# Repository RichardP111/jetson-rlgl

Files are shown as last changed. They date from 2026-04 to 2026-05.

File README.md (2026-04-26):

<div align="center">

# Jetson RLGL

### A real-time, AI *Red Light, Green Light* Game

A self-officiating *Squid Game*-style game built on the NVIDIA Jetson Orin Nano. The system tracks every player simultaneously with YOLOv8-pose accelerated through TensorRT, detects motion during the red phase to the pixel, identifies eliminated players by shirt colour, and projects the entire game — animated overlays, dramatic eliminations, winner sequences — in real time at 60 FPS.

<br />







<br />

**~30 ms inference · 60 FPS display · multi-player tracking · zero human referee required**

</div>

---

## Table of Contents

- [Performance at a glance](#performance-at-a-glance)
- [How it plays](#how-it-plays)
- [Architecture](#architecture)
- [Hardware](#hardware)
- [Installation](#installation)
- [Running the game](#running-the-game)
- [Calibration tools](#calibration-tools)
- [Configuration](#configuration)
- [Optimisation notes](#optimisation-notes)
- [Troubleshooting](#troubleshooting)
- [Project structure](#project-structure)
- [Credits](#credits)

---

## Performance at a glance

| Metric | Value | How |
|---|---|---|
| Pose inference | **~15–30 ms** | YOLOv8n-pose exported to TensorRT FP16, pre-resized to 640×384 |
| Display loop | **60 FPS** | Decoupled from inference via dedicated `PoseWorker` thread |
| Camera capture | **60 FPS** | CSI IMX219 → NVMM zero-copy → hardware scaler |
| Colour analysis | **~0 ms typical** | Lazy: only runs at catch / win events, not every frame |
| End-to-end latency | **~50 ms** | From a player moving to elimination on screen |

Tested on Jetson Orin Nano (8 GB) with `MAXN` power mode, `jetson_clocks` locked, JetPack 6.0.

---

## How it plays

```
┌────────────────────────────────────────────────────────────┐
│                    START SCREEN                             │
│            Raise a palm for 2 seconds to begin              │
└──────────────────────────────┬─────────────────────────────┘
                               │
                       3 … 2 … 1 …
                               │
┌──────────────────────────────▼─────────────────────────────┐
│                  🟢  GREEN LIGHT                            │
│        Head faces away · Players advance toward finish      │
└──────────────────────────────┬─────────────────────────────┘
                               │  random 3–6 s
┌──────────────────────────────▼─────────────────────────────┐
│                       TURNING                               │
│             Servo rotates · 0.5 s grace window              │
└──────────────────────────────┬─────────────────────────────┘
                               │
┌──────────────────────────────▼─────────────────────────────┐
│                  🔴  RED LIGHT                              │
│      Head faces players · Per-player motion check active    │
│                                                             │
│   Movement detected ──► CAUGHT — return to start            │
│   Timer expires     ──► Back to GREEN                       │
│   Beam crossed      ──► WINNER sequence                     │
└─────────────────────────────────────────────────────────────┘
```

Every player has an independent baseline position the moment red starts. They're checked individually each frame — motion in one person doesn't affect the others. Caught players are identified by shirt colour and announced over a PA speaker by `espeak` TTS: *"Player in the blue shirt — return to the start!"*

---

## Architecture

The system is built around a strict producer-consumer split. Inference runs on its own thread, the camera runs on its own thread, and the main game loop never blocks on either.

```
┌─────────────────────────┐    ┌─────────────────────────┐
│      Camera (thread)    │    │   PoseWorker (thread)   │
│                         │    │                         │
│   nvarguscamerasrc      │───▶│   YOLOv8-pose (TRT FP16)│
│   1280×720 @ 60 FPS     │    │   ~15–30 ms / frame     │
│   ISP-tuned colour      │    │   ByteTrack persistent  │
└──────────┬──────────────┘    └────────────┬────────────┘
           │                                │
           │  latest frame                  │  latest pose
           │  (lock-protected)              │  (lock-protected)
           ▼                                ▼
┌─────────────────────────────────────────────────────────┐
│                    GameEngine (main thread)              │
│                                                          │
│   ┌────────────┐  ┌───────────┐  ┌────────────────────┐ │
│   │ State FSM  │  │   Audio   │  │  ServoController   │ │
│   │ GREEN/RED  │  │  Manager  │  │  (PCA9685, thread) │ │
│   └────────────┘  └───────────┘  └────────────────────┘ │
│                                                          │
│   ┌──────────────────────────────────────────────────┐  │
│   │  UIRenderer — Pygame, 60 FPS Material 3 UI       │  │
│   └──────────────────────────────────────────────────┘  │
└─────────────────────────────────────────────────────────┘
```

Critically, the main loop reads the *most recent* camera frame and the *most recent* pose result — never waits for either. If inference takes 30 ms and the display does 16 ms frames, the game stays at 60 FPS and simply re-uses the most recent pose data for ~2 frames at a time. The eye doesn't notice; the inference budget no longer caps the display.

---

## Hardware

### Bill of materials

| Component | Model | Interface | Notes |
|---|---|---|---|
| Compute | NVIDIA Jetson Orin Nano (8 GB) | — | JetPack 6.0+ |
| Camera | Waveshare IMX219-120 (CSI) | CSI / nvarguscamerasrc | 60 FPS, 120° FOV |
| Servo driver | PCA9685 16-channel PWM | I²C bus 7 @ 0x40 | External 5–6 V supply |
| Servo | Standard 180° hobby servo | PCA9685 ch. 0 | DS3218 or similar |
| Finish line | Laser break-beam module | GPIO physical pin 7 | Active LOW, PUD_UP |
| Audio | PA speaker | 3.5 mm or USB DAC | `espeak` TTS supported |
| Display | Monitor / projector | DP | Native 1920×1080 |

### Wiring

**PCA9685 → Jetson 40-pin header**

| PCA9685 | Jetson | Function |
|:---:|:---:|:---|
| VCC | Pin 1 (3.3 V) | Logic |
| GND | Pin 6 | Ground |
| SDA | Pin 3 | I²C-7 SDA |
| SCL | Pin 5 | I²C-7 SCL |
| **V+** | **External 5–6 V** | **Servo power — DO NOT use Jetson 5V** |

> ⚠️ **Power servos from a separate 5–6 V supply.** Servos can briefly draw >1 A under load; the Jetson rail will sag and reset the board.

**Laser break-beam → Jetson**

| Sensor | Jetson | Note |
|:---:|:---:|:---|
| Signal | Pin 7 (BOARD) | Active LOW, internal pull-up |
| VCC | Pin 1 / 17 (3.3 V) | Most modules also accept 5 V |
| GND | Any GND | Common ground with Jetson |

**Pre-flight verification**

```bash
v4l2-ctl --list-devices         # Camera should appear at /dev/video0
sudo i2cdetect -y 7             # PCA9685 should appear as 40 in the grid
gpio readall                    # Optional — sanity-check pin states
```

---

## Installation

### Prerequisites

- Jetson Orin Nano with JetPack 6.0 or later
- CUDA, cuDNN, TensorRT (all bundled with JetPack)
- A working DISPLAY — local HDMI, or NoMachine for headless
- ~3 GB free disk space

### Setup

```bash
git clone https://github.com/RichardP111/jetson-rlgl.git
cd jetson-rlgl
bash setup.sh
```

`setup.sh` installs `ultralytics`, `pygame`, `adafruit-circuitpython-pca9685`, `Jetson.GPIO`, `espeak`, `v4l-utils`, and `i2c-tools`. It also verifies the camera node and I²C bus.

### One-time TensorRT export

The repo ships with `yolov8n-pose.pt`. On first run the engine is auto-built — but you can trigger it manually for predictable startup time:

```bash
yolo export model=yolov8n-pose.pt format=engine half=True imgsz=480 device=0
```

This takes **~5 minutes** the first time. The resulting `yolov8n-pose.engine` is what `vision.py` actually loads.

### Lock the Jetson at full clocks (recommended)

```bash
sudo nvpmodel -m 0          # MAXN power mode
sudo jetson_clocks          # Pin clocks to maximum
```

Without this, dynamic frequency scaling causes inference times to fluctuate by ~30%.

### Assets

Drop your media into the assets folders:

**`assets/sounds/`** — all optional; `espeak` TTS is the fallback.

| File | Used for |
|---|---|
| `bgm.mp3` | Background music loop |
| `green_light.wav` | Green-light cue |
| `red_light.wav` | Red-light cue |
| `mugunghwa.wav` | Korean "freeze" phrase |
| `eliminated.wav` | Caught sting |
| `winner.wav` | Victory fanfare |
| `tick.wav` / `chime.wav` | Countdown / generic |

**`assets/fonts/`** — `GoogleSans-Bold.ttf` recommended (Material 3 default).

---

## Running the game

```bash
bash launcher.sh
```

`launcher.sh` is a menu-driven controller that handles the hairy stuff: display permissions, `nvargus-daemon` restart, audio device routing, and Docker container coordination. Pick option **3** to start the game.

To bypass the launcher (developer mode):

```bash
export DISPLAY=:0
python3 main.py
```

### Debug hotkeys

These are live during gameplay and useful for testing without playing through the full FSM.

| Key | Action |
|:---:|---|
| `H` | Toggle on-screen debug panel (FPS, inference ms, player count) |
| `G` | Force GREEN LIGHT |
| `R` | Force RED LIGHT |
| `W` | Force WINNER screen |
| `E` | Simulate elimination |
| `SPACE` | Skip palm-raise gesture |
| `ESC` | Graceful shutdown |

---

## Calibration tools

Three standalone GUIs are bundled to handle hardware bring-up, tuning, and debugging without modifying the game code. Each writes a snippet you paste back into `config.py` (or `hardware.py` for the camera).

### `test_camera.py` — ISP & colour

```bash
python3 test_camera.py
```

Live preview with sliders for every `nvarguscamerasrc` knob — white balance, saturation, exposure, gain caps, ISP digital gain, temporal noise reduction, edge enhancement. Tabbed by category. Shows the GStreamer pipeline string updating in real time, and emits a drop-in `_gstreamer_pipeline()` snippet for `hardware.py`. Includes presets for fluorescent gym lighting, daylight, and warm tungsten.

**Most useful for:** colours looking dull or grey, sensor noise in low light, AE/AWB hunting causing blur cycles.

### `test_servo.py` — PCA9685

```bash
python3 test_servo.py
```

Animated semicircular gauge, manual angle and pulse-width sliders, four automated tests (sweep / step response / hold / random walk), I²C bus scanner, PCA9685 ping, and a guided MIN/MAX calibration wizard. Hard-stop protection — won't drive past mechanical limits once calibrated. Generates the full servo block for `config.py`.

**Most useful for:** first-time install, finding your specific servo's real `MIN_US`/`MAX_US`, debugging jitter or buzzing.

### `tets_lazer.py` — Break-beam

```bash
python3 tets_lazer.py
```

Live beam-state visualisation, scrolling 10-second history strip (great for spotting flaky sensors), debounce calibration with samples × window, and three automated tests:

- **Alignment helper** — confirms a stable beam for 10 seconds straight
- **Drift watch** — 60-second false-positive logger
- **Latency probe** — measures debounce delay across 10 real crossings

GPIO diagnostics tab runs all the standard checks (gpio group membership, gpiochip device list, current pin state).

**Most useful for:** the day-of-event debugging when a previously-working sensor has decided to act up, alignment after physical setup, dialing in debounce so a single crossing isn't counted as five wins.

All three tools fall back to **simulation mode** when hardware isn't available, so they're useful for UI testing on a laptop too.

---

## Configuration

Everything tunable lives in `config.py`. The values most worth knowing:

### Gameplay timing

```python
GREEN_LIGHT_MIN  = 3.0   # shortest green-light phase
GREEN_LIGHT_MAX  = 6.0   # longest green-light phase
RED_LIGHT_MIN    = 2.0   # shortest red-light phase
RED_LIGHT_MAX    = 5.0   # longest red-light phase
GRACE_PERIOD     = 0.5   # delay after RED before motion can catch
MOTION_THRESHOLD = 15.0  # pixels of movement to trigger elimination
CAUGHT_HOLD      = 3.5   # screen pause after a catch
```

`MOTION_THRESHOLD` is in pixel space at 1280×720 capture resolution. If you change camera resolution, scale this proportionally — at 960×540 you'd want `~11`.

### Difficulty presets

For age-appropriate scaling, three pre-tuned profiles ship in `config.py`:

| Preset | Green min/max | Red min/max | Motion px |
|---|:---:|:---:|:---:|
| Easy | 5.0 – 9.0 s | 4.0 – 7.0 s | 20 |
| **Normal** | 3.5 – 7.0 s | 3.0 – 5.5 s | 15 |
| Hard | 2.5 – 5.0 s | 2.0 – 4.0 s | 10 |

### Hardware pinout

```python
I2C_BUS         = 7        # Bus 7 on Orin Nano 40-pin header
PCA9685_ADDRESS = 0x40
SERVO_CHANNEL   = 0
SERVO_FREQ      = 50       # Hz; some cheap servos prefer 60
SERVO_MIN_PULSE = 500      # µs — calibrate per-servo with servo_tuner.py
SERVO_MAX_PULSE = 2500     # µs
LASER_PIN       = 7        # BOARD numbering
```

---

## Optimisation notes

The system has been optimised hard. The key wins, in order of impact:

1. **TensorRT FP16 export.** ~100 ms PyTorch inference → ~15–30 ms TRT inference. Single biggest win.
2. **Pre-resize the YOLO input.** Feeding 1920×1080 frames into a 480-input model wastes ~5 ms per frame on a CPU-side letterbox. Pre-sizing to 640×384 in OpenCV cuts that to ~1 ms.
3. **Async `PoseWorker` thread.** Decouples display loop from inference. Display fps is now bounded by `FPS_CAP`, not by YOLO.
4. **Lazy shirt-colour detection.** Eleven `cv2.inRange` operations per detected player, every frame, was costing ~3–6 ms with multiple players. Now runs only at catch / winner events — saves several ms continuously.
5. **ISP-tuned camera pipeline.** Saturation boost, white balance lock, digital gain capped at 1× to kill amplification noise, edge enhancement disabled. Better-looking image *and* faster — no more per-frame CPU colour correction.
6. **Power mode.** `nvpmodel -m 0` + `jetson_clocks` is free 30% perf.

If inference is still slow after all of this, drop to `imgsz=384` in the export command. INT8 export shaves another few milliseconds but requires calibration data and slightly hurts keypoint accuracy on small bodies.

---

## Troubleshooting

| Symptom | First thing to check |
|---|---|
| **Black camera feed** | `v4l2-ctl --list-devices` — if empty, run `sudo /opt/nvidia/jetson-io/jetson-io.py` and enable IMX219 |
| **PCA9685 not detected** | `sudo i2cdetect -y 7` — should show `40`. If not, check SDA/SCL wiring |
| **GPIO permission denied** | `sudo usermod -aG gpio $USER && sudo reboot` |
| **Servo jitters / buzzes** | Power supply too weak. Use a separate 5–6 V supply, ≥1 A. Common ground required. |
| **Beam triggers spuriously** | Run `laser_tuner.py` → Drift Watch test. Increase debounce samples to 5+ |
| **Inference > 50 ms** | Confirm `.engine` is loading, not `.pt`. Check `sudo nvpmodel -q` shows MAXN |
| **Display fps < 60** | Check `FPS_CAP=60` in `config.py`. Confirm `PoseWorker` is publishing pose only, not frames |
| **Colours look grey / dull** | Run `camera_tuner.py` — bump saturation to 1.4, lock AWB after calibration |
| **NoMachine no display** | `export DISPLAY=:1` (NoMachine virtual session, not `:0`) |

For each hardware subsystem, the matching tuner script has a dedicated **Troubleshooting** tab with extended checklists.

---

## Project structure

```
jetson-rlgl/
├── main.py                 Entry point — initialises subsystems, runs engine
├── game.py                 GameEngine — finite-state machine, motion logic
├── vision.py               ProPoseTracker (TRT) + PoseWorker (async thread)
├── ui.py                   UIRenderer — Material 3 Pygame screens
├── audio.py                AudioManager — SFX + music + espeak TTS
├── hardware.py             Camera (CSI), ServoController (PCA9685), LaserBreakBeam
├── config.py               All tunable constants + difficulty presets
│
├── camera_tuner.py         ISP / GStreamer live tuner
├── servo_tuner.py          PCA9685 calibration & test rig
├── laser_tuner.py          GPIO break-beam debugger
│
├── setup.sh                One-shot dependency installer
├── launcher.sh              Menu-driven game launcher
│
├── yolov8n-pose.pt         Source model (4 MB)
├── yolov8n-pose.engine     TensorRT engine, auto-generated on first run (~10 MB)
│
├── assets/
│   ├── fonts/              GoogleSans .ttf files
│   └── sounds/             .wav and .mp3 audio
│
└── hardware_tests/         Standalone subsystem test scripts
```

---

## Built with

[NVIDIA Jetson](https://www.nvidia.com/en-us/autonomous-machines/embedded-systems/) ·
[TensorRT](https://developer.nvidia.com/tensorrt) ·
[YOLOv8 by Ultralytics](https://github.com/ultralytics/ultralytics) ·
[OpenCV](https://opencv.org/) ·
[GStreamer](https://gstreamer.freedesktop.org/) ·
[Pygame](https://www.pygame.org/) ·
[Adafruit CircuitPython](https://github.com/adafruit/Adafruit_CircuitPython_PCA9685) ·
[espeak](http://espeak.sourceforge.net/)

---
## Acknowledgements

### Models
- **YOLOv8-pose** by [Ultralytics](https://github.com/ultralytics/ultralytics)
  — released under [AGPL-3.0](https://github.com/ultralytics/ultralytics/blob/main/LICENSE).
  The bundled `yolov8n-pose.pt` and the derived `yolov8n-pose.engine`
  remain under AGPL. Code in this repository that loads or wraps these
  weights is intended for personal and educational use; commercial
  deployment requires either an Ultralytics enterprise license or
  AGPL-compatible release of all dependent code.

### Fonts
- **Google Sans** by Google — licensed under
  [SIL Open Font License v1.1](assets/fonts/OFL.txt). Redistributed
  unmodified.

### Inspiration
- The *Red Light, Green Light* game itself is a traditional
  playground game in the public domain.
- Aesthetic and dramatic framing inspired by *Squid Game* (Netflix, 2021).
  This project is not affiliated with, endorsed by, or sponsored by
  Netflix or any related entity. All series-specific trademarks,
  character likenesses, and copyrighted material remain the property
  of their respective owners.

### Author
Built by **Richard P** and **Cindy X** for STEM Day 2026.

Released under the [MIT License](LICENSE) — note that this license
applies to the project's original code only. Bundled third-party
assets (fonts, model weights) retain their original licenses.

<br />

<div align="center">

*"red light…   green light…"*

</div>

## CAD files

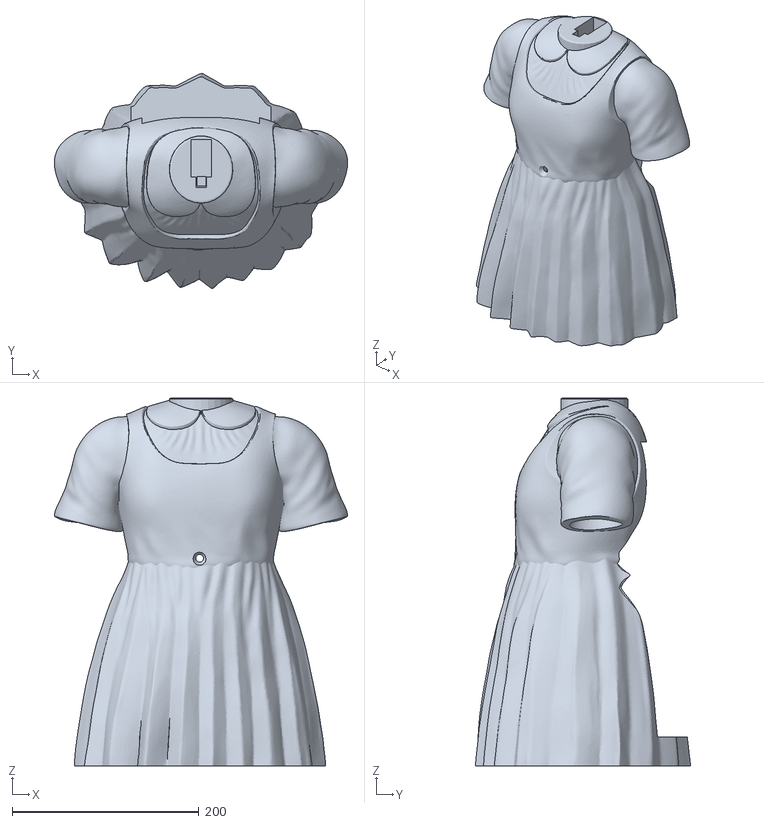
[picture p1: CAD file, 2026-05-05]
3D_files/RLGL BODY.stl
314.2 x 230.4 x 394.2

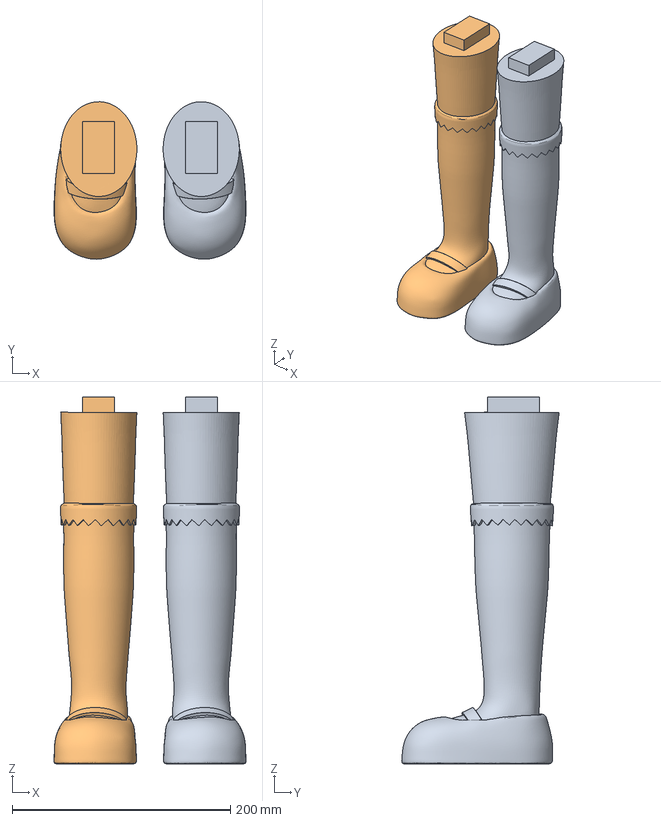
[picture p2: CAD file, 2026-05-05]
3D_files/RLGL LEGS.3mf
175.9 x 144.4 x 336.5 mm
Leg_L.stl
leg_R.stl

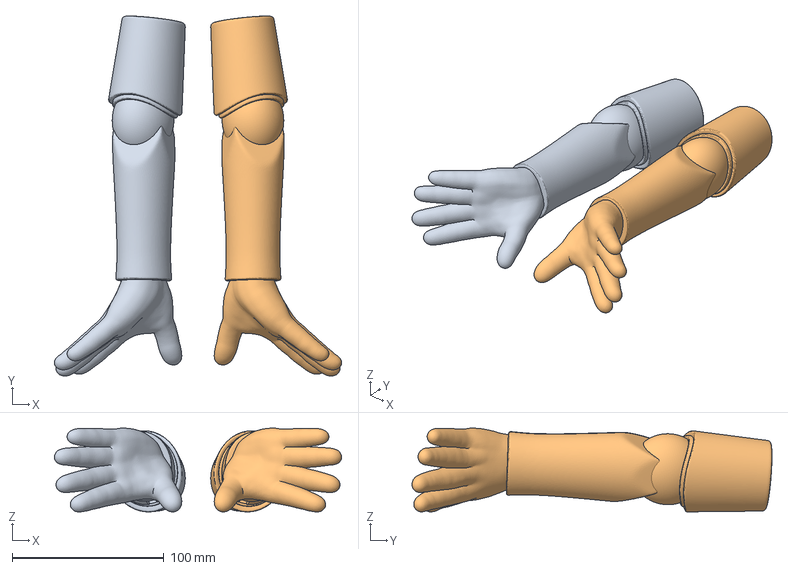
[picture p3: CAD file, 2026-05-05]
3D_files/RLGL ARMS.3mf
189.6 x 237.5 x 55.3 mm
arm_L.stl
arm_R.stl

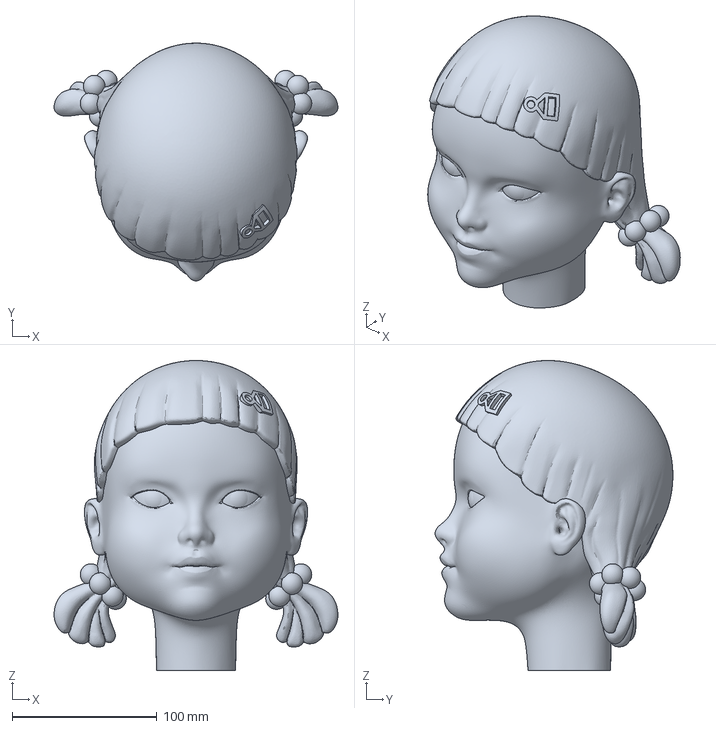
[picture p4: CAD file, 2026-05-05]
3D_files/RLGL HEAD.3mf
196.2 x 164.4 x 214.3 mm

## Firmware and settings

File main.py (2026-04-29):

#!/usr/bin/env python3
# -*- coding: utf-8 -*-

"""
===============================================================================
Project:      Red Light Green Light (Jetson Orin Nano)
File:         main.py
Description:  Entry point — initialises all subsystems and hands off to GameEngine.

Author:       Richard Pu
Last Updated: April 2026

To Run:
Run laucher.sh OR VS CODE: Ctrl+Shift+B
===============================================================================
"""

from __future__ import annotations

import argparse
import os
import sys
import traceback

# Headless support (must be set before pygame imports a display module)
if "--headless" in sys.argv or os.environ.get("RLGL_HEADLESS") == "1":
    os.environ.setdefault("SDL_VIDEODRIVER", "dummy")
    os.environ.setdefault("SDL_AUDIODRIVER", "dummy")
else:
    # Apr 2026 — force GPU compositing on Jetson Orin Nano. Pygame's
    # default SDL2 backend on Linux silently falls back to a software
    # blit pipeline, which pegs a single CPU core and leaves the GPU
    # idle. Telling SDL to use the OpenGL ES 2 renderer offloads the
    # final framebuffer composite to the Jetson's integrated GPU and
    # frees the CPU up for camera + pose work.
    #
    # Setting these as DEFAULTS via setdefault() lets the user override
    # them from the shell if a particular system needs something else
    # (e.g. SDL_RENDER_DRIVER=opengl on a desktop dev box).
    os.environ.setdefault("SDL_RENDER_DRIVER", "opengles2")
    os.environ.setdefault("SDL_RENDER_VSYNC", "1")
    # On Jetson, KMSDRM gives us a clean fullscreen path without going
    # through X11; keep it as a fallback if the user is running headless
    # without a desktop.
    if not os.environ.get("DISPLAY") and not os.environ.get("WAYLAND_DISPLAY"):
        os.environ.setdefault("SDL_VIDEODRIVER", "kmsdrm")

import pygame

# Audio pre_init must happen BEFORE pygame.init() to set the mixer buffer
import audio as audio_mod

audio_mod.pre_init()

from audio import AudioManager
from config import (
    DISPLAY_H,
    DISPLAY_W,
    FPS_CAP,
    IDENTIFICATION_MODE,
    USE_LASER,
    USE_TAPE_FINISH,
    WINDOW_TITLE,
)
from game import GameEngine
from hardware import Camera, LaserBreakBeam, ServoController
from ui import UIRenderer
from vision import PlayerDescriber, PoseWorker, ProPoseTracker


# ---------------------------------------------------------------------------
# Pretty banner
# ---------------------------------------------------------------------------
_BANNER = r"""
╔══════════════════════════════════════════════════════════════════════════╗
║                                                                          ║
║      RED LIGHT, GREEN LIGHT  ·  Jetson Orin Nano  ·  Apr 2026            ║
║                                                                          ║
║      • Camera + (optional) laser break-beam finish detection             ║
║      • YOLOv8-pose tracking, palm-raise to start                         ║
║      • {id_mode_pad}player identification (VLM / CLIP / colour)        ║
║      • Auto-easing difficulty if a round drags on                        ║
║      • Kahoot-style leaderboard with podium photos                       ║
║                                                                          ║
║      HOTKEYS:  H or Ctrl+D  Dev panel                                    ║
║                G              Force GREEN  (begins round if needed)      ║
║                R              Force RED                                  ║
║                W              Debug-finish first remaining player        ║
║                L              Jump to leaderboard                        ║
║                F              Toggle DEBUG_SKIP_FINISH (no finish line)  ║
║                SPACE          Bypass palm gate / Play again              ║
║                ESC            Quit                                       ║
║      DEV-ONLY: 1 servo→face   2 servo→away   3 laser status              ║
║                4 chime         5 TTS test                                ║
║                                                                          ║
╚══════════════════════════════════════════════════════════════════════════╝
"""


def _print_banner() -> None:
    print(_BANNER.format(id_mode_pad=f"{IDENTIFICATION_MODE:>5} "))
    print(f"  USE_LASER       = {USE_LASER}")
    print(f"  USE_TAPE_FINISH = {USE_TAPE_FINISH}")
    print(f"  ID mode         = {IDENTIFICATION_MODE}")
    print()


# ---------------------------------------------------------------------------
# Main
# ---------------------------------------------------------------------------
def main() -> int:
    parser = argparse.ArgumentParser()
    parser.add_argument("--headless", action="store_true", help="Run with dummy SDL drivers (no display, no audio device)")
    parser.add_argument("--fullscreen", action="store_true", default=True, help="Run fullscreen (default)")
    parser.add_argument("--windowed", dest="fullscreen", action="store_false", help="Run in a window (useful for dev)")
    args = parser.parse_args()

    _print_banner()

    pygame.init()
    pygame.display.set_caption(WINDOW_TITLE)
    # Apr 2026 — pygame.SCALED routes the framebuffer through SDL2's
    # GPU-accelerated renderer (matched with SDL_RENDER_DRIVER=opengles2
    # set above) and DOUBLEBUF gives us a proper backbuffer flip rather
    # than a software blit. Together with the SDL hints these flags are
    # what actually gets the Jetson GPU off idle.
    base_flags = pygame.SCALED | pygame.DOUBLEBUF
    if args.fullscreen and not args.headless:
        base_flags |= pygame.FULLSCREEN
    try:
        screen = pygame.display.set_mode((DISPLAY_W, DISPLAY_H), base_flags, vsync=1)
    except Exception as exc:
        # SDL_RENDER_DRIVER=opengles2 + SCALED can fail on systems without
        # a working GLES2 stack; fall back to plain DOUBLEBUF so we at
        # least keep DOUBLEBUF's flip-buffer benefit.
        print(f"[main] GPU display path unavailable ({exc}); falling back to plain DOUBLEBUF")
        fallback_flags = pygame.DOUBLEBUF
        if args.fullscreen and not args.headless:
            fallback_flags |= pygame.FULLSCREEN
        screen = pygame.display.set_mode((DISPLAY_W, DISPLAY_H), fallback_flags)
    pygame.mouse.set_visible(False)
    clock = pygame.time.Clock()

    # ---- Construct subsystems ----------------------------------------
    camera: Camera | None = None
    servo: ServoController | None = None
    laser: LaserBreakBeam | None = None
    tracker: ProPoseTracker | None = None
    pose_worker: PoseWorker | None = None
    audio: AudioManager | None = None
    ui: UIRenderer | None = None
    describer: PlayerDescriber | None = None

    rc = 0
    try:
        camera = Camera()
        servo = ServoController()
        laser = LaserBreakBeam()
        tracker = ProPoseTracker()
        pose_worker = PoseWorker(camera, tracker)
        audio = AudioManager()
        ui = UIRenderer(screen)
        ui.set_audio_hook(audio)  # let the leaderboard fire podium SFX directly
        describer = PlayerDescriber()
        print("[main] Warming up describer...")
        if IDENTIFICATION_MODE == "vlm":
            describer._ensure_vlm()
        elif IDENTIFICATION_MODE == "clip":
            describer._ensure_clip()

        engine = GameEngine(
            camera=camera,
            servo=servo,
            laser=laser,
            tracker=tracker,
            audio=audio,
            ui=ui,
            pose_worker=pose_worker,
            describer=describer,
        )
        engine.run(clock)
    except SystemExit:
        pass
    except KeyboardInterrupt:
        print("\n[main] Interrupted.")
    except Exception as exc:
        print(f"[main] Fatal: {exc}")
        traceback.print_exc()
        rc = 1
    finally:
        # Reverse-order teardown
        try:
            if pose_worker is not None:
                pose_worker.stop()
        except Exception:
            pass
        try:
            if camera is not None:
                camera.release()
        except Exception:
            pass
        try:
            if servo is not None:
                servo.cleanup()
        except Exception:
            pass
        try:
            if laser is not None:
                laser.cleanup()
        except Exception:
            pass
        try:
            if audio is not None:
                audio.cleanup()
        except Exception:
            pass
        try:
            pygame.quit()
        except Exception:
            pass

    return rc


if __name__ == "__main__":
    raise SystemExit(main())

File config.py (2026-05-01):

#!/usr/bin/env python3
# -*- coding: utf-8 -*-

"""
===============================================================================
Project:      Red Light Green Light (Jetson Orin Nano)
File:         config.py
Description:  Global constants, M3 Expressive palette, tunable difficulty,
              animation timings, and hardware pin definitions.

Author:       Richard Pu
Last Updated: April 2026
===============================================================================
"""

import os
import platform

# ---------------------------------------------------------------------------
# Platform detection
# ---------------------------------------------------------------------------
IS_WINDOWS = platform.system() == "Windows"
IS_LINUX = platform.system() == "Linux"

# ---------------------------------------------------------------------------
# Paths
# ---------------------------------------------------------------------------
BASE_DIR = os.path.dirname(os.path.abspath(__file__))
ASSETS_DIR = os.path.join(BASE_DIR, "assets")
FONTS_DIR = os.path.join(ASSETS_DIR, "fonts")
SOUNDS_DIR = os.path.join(ASSETS_DIR, "sounds")
PROFILES_DIR = os.path.join(ASSETS_DIR, "player_profiles")
STATS_FILE = os.path.join(ASSETS_DIR, "session_stats.json")
LEADERBOARD_FILE = os.path.join(ASSETS_DIR, "leaderboard.json")
FONT_PATH = os.path.join(FONTS_DIR, "GoogleSans.ttf")

# ---------------------------------------------------------------------------
# Display
# ---------------------------------------------------------------------------
DISPLAY_W = 1920
DISPLAY_H = 1080
FPS_CAP = 60
FULLSCREEN = True
WINDOW_TITLE = "Red Light, Green Light"

# ---------------------------------------------------------------------------
# Camera
# ------------_--------------------------------------------------------------
CAM_W = 1920
CAM_H = 1080
CAM_FPS = 30
YOLO_SKIP_FRAMES = 2  # How many camera frames between YOLO inferences
HOME_CAM_BOX_FRACTION = 0.6  # Camera occupies 60% of usable width on home screen

# ---------------------------------------------------------------------------
# Material Design 3 "Expressive" palette
# ---------------------------------------------------------------------------

# Surfaces
MD3_BG = (18, 16, 26)
MD3_SURFACE = (28, 26, 38)
MD3_SURFACE_HIGH = (40, 37, 54)
MD3_SURFACE_VAR = (50, 46, 68)
MD3_OUTLINE = (78, 74, 96)

# Primary
MD3_PRIMARY = (188, 162, 255)
MD3_ON_PRIMARY = (28, 0, 90)
MD3_PRIMARY_CONTAINER = (64, 46, 122)
MD3_ON_PRIMARY_CONTAINER = (232, 221, 255)

# Secondary
MD3_SECONDARY = (255, 180, 200)
MD3_ON_SECONDARY = (80, 25, 50)

# Tertiary
MD3_TERTIARY = (120, 220, 232)
MD3_ON_TERTIARY = (0, 55, 62)

# Semantic
MD3_SUCCESS = (168, 232, 178)
MD3_SUCCESS_ON = (0, 74, 24)
MD3_SUCCESS_BG = (36, 70, 44)

MD3_ERROR = (255, 182, 180)
MD3_ERROR_ON = (94, 17, 24)
MD3_ERROR_BG = (92, 36, 40)

MD3_WARNING = (255, 220, 160)
MD3_WARNING_ON = (76, 48, 0)
MD3_WARNING_BG = (96, 64, 16)

MD3_INFO = (180, 210, 255)
MD3_INFO_ON = (8, 36, 92)

# Podium
MD3_GOLD = (255, 215, 96)
MD3_SILVER = (200, 208, 220)
MD3_BRONZE = (217, 150, 100)

# Text
MD3_ON_BG = (235, 228, 245)
MD3_ON_BG_MED = (188, 182, 200)
MD3_ON_BG_DIM = (128, 122, 142)

# Per-state accent (used by the banner)
STATE_COLORS = {
    "START": MD3_PRIMARY,
    "COUNTDOWN": MD3_TERTIARY,
    "GREEN": MD3_SUCCESS,
    "TURNING": MD3_WARNING,
    "RED": MD3_ERROR,
    "CAUGHT": MD3_ERROR,
    "ELIMINATED": MD3_ERROR,  # walk-back banner colour (Apr 2026 rebrand)
    "WINNER": MD3_PRIMARY,
    "START_LINE": MD3_SUCCESS,
    "RETURN": MD3_ERROR,  # legacy alias kept for compatibility
    "LEADERBOARD": MD3_PRIMARY,
}

# ---------------------------------------------------------------------------
# Motion
# ---------------------------------------------------------------------------
MOTION_FAST = 18.0
MOTION_MED = 10.0
MOTION_SLOW = 6.0
BANNER_PULSE_HZ = 1.4

# ---------------------------------------------------------------------------
# Gameplay timing — slower-paced defaults per Apr 2026 design refresh
# ---------------------------------------------------------------------------
DIFFICULTY_PRESETS = {
    "Easy": {
        "green_min": 7.0,
        "green_max": 13.0,
        "red_min": 5.0,
        "red_max": 9.0,
        "motion_px": 28,
    },
    "Normal": {
        "green_min": 1.0,
        "green_max": 2.0,
        "red_min": 4.0,
        "red_max": 7.5,
        "motion_px": 26,
    },
    "Hard": {
        "green_min": 3.5,
        "green_max": 7.0,
        "red_min": 3.0,
        "red_max": 5.5,
        "motion_px": 14,
    },
}
DEFAULT_DIFFICULTY = "Normal"
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

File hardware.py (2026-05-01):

#!/usr/bin/env python3
# -*- coding: utf-8 -*-

"""
===============================================================================
Project:      Red Light Green Light (Jetson Orin Nano)
File:         hardware.py
Description:  Platform-aware hardware abstraction.


Author:       Richard Pu
Last Updated: April 2026
===============================================================================
"""

from __future__ import annotations

import threading
import time
from typing import Any

import cv2  # type: ignore
import numpy as np

from config import (
    CAM_FPS,
    CAM_H,
    CAM_W,
    I2C_BUS,
    IS_LINUX,
    IS_WINDOWS,
    LASER_PIN,
    PCA9685_ADDR,
    SERVO_AWAY_DEG,
    SERVO_CHANNEL,
    SERVO_FACE_DEG,
    SERVO_FREQ,
    SERVO_MAX_US,
    SERVO_MIN_US,
    SERVO_STEP_DEG,
    SERVO_TICK_S,
    USE_LASER,
)

# ---------------------------------------------------------------------------
# Optional Jetson-only imports.
# ---------------------------------------------------------------------------
_ADAFRUIT_OK = False
_GPIO_OK = False

if IS_LINUX:
    try:
        import board  # type: ignore
        import busio  # type: ignore
        from adafruit_pca9685 import PCA9685 as _PCA9685  # type: ignore

        _ADAFRUIT_OK = True
    except (ImportError, AttributeError, NotImplementedError, ValueError):
        _ADAFRUIT_OK = False

    try:
        import Jetson.GPIO as GPIO  # type: ignore

        _GPIO_OK = True
    except (ImportError, AttributeError, RuntimeError):
        _GPIO_OK = False

HARDWARE_AVAILABLE = _ADAFRUIT_OK or _GPIO_OK


# ---------------------------------------------------------------------------
# Camera
# ---------------------------------------------------------------------------
def _gstreamer_pipeline(
    capture_w: int = CAM_W,
    capture_h: int = CAM_H,
    output_w: int = 1920,
    output_h: int = 1080,
    fps: int = CAM_FPS,
) -> str:
    return (
        f"nvarguscamerasrc "
        f"wbmode=2 "
        f"saturation=1.01 "
        f'gainrange="1 8" '
        f'ispdigitalgainrange="1 1" '
        f'exposuretimerange="13000 16000000" '
        f"tnr-mode=2 tnr-strength=0.2 "
        f"exposurecompensation=1.14 "
        f"ee-mode=0 "
        f"aelock=false awblock=false "
        f"! video/x-raw(memory:NVMM), width={capture_w}, height={capture_h}, "
        f"format=NV12, framerate={fps}/1 ! "
        f"nvvidconv flip-method=2 ! "
        f"video/x-raw, width={output_w}, height={output_h}, format=BGRx ! "
        f"videoconvert ! video/x-raw, format=BGR ! "
        f"appsink drop=true max-buffers=1"
    )


class Camera:
    """Threaded camera capture with a single shared frame guarded by a lock.

    Producer: background daemon thread.
    Consumer: main loop calls read() / read_with_id() each frame.
    """

    def __init__(self) -> None:
        self._lock = threading.Lock()
        self._frame: np.ndarray | None = None
        self._running = True
        self._ok = False
        self._backend = "none"
        self._fps_ts = time.time()
        self._fps_count = 0
        self._fps = 0.0
        self._frame_id = 0
        self._cap = self._open()

        self._thread = threading.Thread(target=self._loop, daemon=True, name="cam")
        self._thread.start()
        print(f"[CAM] Backend: {self._backend}  ok={self._ok}")

    def _open(self) -> Any | None:
        video_capture = getattr(cv2, "VideoCapture", None)
        if video_capture is None:
            self._backend = "none"
            self._ok = False
            return None

        if IS_WINDOWS:
            return self._open_default(video_capture)

        cap_gstreamer = int(getattr(cv2, "CAP_GSTREAMER", 0))
        cap = video_capture(_gstreamer_pipeline(), cap_gstreamer)
        if cap.isOpened():
            self._backend = "gstreamer"
            self._ok = True
            return cap

        cap_v4l2 = int(getattr(cv2, "CAP_V4L2", 0))
        cap = video_capture(0, cap_v4l2)
        if cap.isOpened():
            cap.set(int(getattr(cv2, "CAP_PROP_FRAME_WIDTH", 3)), CAM_W)
            cap.set(int(getattr(cv2, "CAP_PROP_FRAME_HEIGHT", 4)), CAM_H)
            cap.set(int(getattr(cv2, "CAP_PROP_FPS", 5)), CAM_FPS)
            cap.set(int(getattr(cv2, "CAP_PROP_BUFFERSIZE", 38)), 1)
            self._backend = "v4l2"
            self._ok = True
            return cap

        return self._open_default(video_capture)

    def _open_default(self, video_capture: Any | None = None) -> Any | None:
        if video_capture is None:
            video_capture = getattr(cv2, "VideoCapture", None)
            if video_capture is None:
                self._backend = "none"
                self._ok = False
                return None

        cap = video_capture(0)
        if cap.isOpened():
            cap.set(int(getattr(cv2, "CAP_PROP_FRAME_WIDTH", 3)), CAM_W)
            cap.set(int(getattr(cv2, "CAP_PROP_FRAME_HEIGHT", 4)), CAM_H)
            self._backend = "default"
            self._ok = True
            return cap
        self._backend = "none"
        self._ok = False
        return None

    def _loop(self) -> None:
        while self._running:
            if self._cap is not None and self._ok:
                ret, frame = self._cap.read()
                if ret and frame is not None:
                    with self._lock:
                        self._frame = frame
                        self._frame_id += 1
                    self._fps_count += 1
                    now = time.time()
                    if now - self._fps_ts >= 1.0:
                        self._fps = self._fps_count / (now - self._fps_ts)
                        self._fps_count = 0
                        self._fps_ts = now
                else:
                    time.sleep(0.01)
            else:
                time.sleep(0.033)
            time.sleep(0.001)

    def read(self) -> np.ndarray | None:
        with self._lock:
            if self._frame is None:
                return None
            return self._frame.copy()

    def read_with_id(self) -> tuple[np.ndarray | None, int]:
        """Return a copy of the latest frame and a monotonic frame id.

        The id is incremented each time the camera thread stores a new frame.
        Callers can use it to skip expensive work when no new frame arrived.
        """
        with self._lock:
            if self._frame is None:
                return None, self._frame_id
            return self._frame.copy(), self._frame_id

    @property
    def ok(self) -> bool:
        return self._ok

    @property
    def backend(self) -> str:
        return self._backend

    @property
    def fps(self) -> float:
        return self._fps

    def release(self) -> None:
        self._running = False
        self._thread.join(timeout=1.5)
        if self._cap is not None:
            try:
                self._cap.release()
            except Exception:
                pass
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

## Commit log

2026-04-19 Refactor AudioManager to use player_label in elimination announcements; update GameEngine to integrate YOLO tracking and color analysis for player identification; replace PoseTracker with ProPoseTrac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
    [audio.py, game.py, test_laser.py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]
2026-04-19 Refactor vision.py: Enhance shirt color detection and implement pose tracking with skeleton overlay
    - Removed the old ColorAnalyzer class and replaced it with a more efficient get_shirt_colour function using HSV color space.
    - Introduced a new PoseTracker class that wraps YOLOv8-pose for persistent tracking and skeleton drawing.
    - Added functionality to process frames, extract keypoints, and draw skeletons on the detected persons.
    - Implemented palm-raise gesture detection and finish-line tape detection based on pose data.
    - Improved code organization and readability by restructuring functions and constants.
    [audio.py, config.py, game.py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]
2026-04-21 Refactor audio and hardware management: Implement Docker compatibility and enhance camera initialization
2026-04-21 Update display and camera settings: Increase FPS cap and resolution for improved performance
2026-04-22 Refactor audio settings and optimize frame processing: Update audio frequency, adjust camera settings, and implement YOLO frame skipping for improved performance
    [audio.py, config.py, game.py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]
2026-04-22 Enhance PoseTracker: Add frame count tracking and optimize shirt color caching logic
2026-04-24 Major changes to UI with design language updates - Consolidated imports and removed unnecessary exception handling for config. - Enhanced shirt color detection logic to handle red color ranges more e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
2026-04-24 Bug fixes to run on Jetson Nano
    [config.py, hardware.py, main.py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]
2026-04-25 feat: Implement PoseWorker for threaded YOLO inference to improve FPS
    - Added PoseWorker class to run YOLO inference on a separate thread, decoupling it from the main Pygame loop.
    - Updated main.py to initialize PoseWorker and pass it to GameEngine.
    - Enhanced UI rendering in ui.py to support new camera rendering methods and layout adjustments.
    - Introduced launcher.sh for environment setup and game engine launching, including display configuration options.
    - Refactored various drawing methods in UIRenderer to accommodate new layout and rendering requirements.
    - Improved shadow rendering and UI elements for better visual consistency and performance.
2026-04-25 feat: Update YOLO configuration and improve camera rendering in UI
2026-04-25 feat: Increase camera FPS to 60 and disable sharpness; update YOLO tracking parameters
2026-04-26 feat: Refactor pose processing and enhance shirt color detection; optimize frame handling in YOLO
2026-04-26 feat: Enhance launcher script with hardware tests and update vision processing
    - Added options for testing camera, servo, and laser in launcher.sh.
    - Updated the case structure to handle new test options and exit.
    - Removed unused camera enhancement parameters from vision.py.
    - Simplified the process_frame method in ProPoseTracker by removing unnecessary comments and code related to camera enhancements.
2026-04-26 Added laser hardware testing
2026-04-27 Refactor vision.py: Enhance color detection, add line detection, and improve player description
    - Introduced a new LineDetector class for detecting start and finish lines using HSV color masking.
    - Refactored color detection logic into a separate _dominant_colour function for better reusability.
    - Updated get_shirt_colour and get_lower_colour functions to utilize the new color detection method.
    - Added PhotoCapture class for cropping players from frames and assessing image quality.
    - Implemented PlayerDescriber class to generate natural language descriptions of players using VLM and CLIP models.
    - Improved error handling and fallback mechanisms for model loading and inference.
    - Enhanced pro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
    [audio.py, config.py, game.py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]
2026-04-28 Enhance launcher.sh for School and Home modes: streamline display setup and NoMachine configuration; improve camera feed rendering in ui.py with optimized OpenCV scaling.
2026-04-28 Refactor LineDetector for orientation flip in April 2026
    - Updated detect_start to search the top two-thirds of the frame for the start line, reflecting the new orientation where the start line is now far from the camera.
    - Adjusted detect_finish to focus on the bottom two-thirds of the frame for the finish line, as it is now closer to the camera.
    - Modified is_behind_start and has_crossed_finish methods to accommodate the new orientation, ensuring correct detection of player positions relative to the start and finish lines.
    [config.py, game.py, hardware.py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]
2026-04-28 Fix: Ensure proper exception handling in PoseWorker thread join method
    [config.py, game.py, main.py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]
2026-04-29 Add line detection functionality and related tests
    - Implemented line detection using contours and fitted lines in vision.py.
    - Updated LineDetector class to handle start and finish line detection with locking mechanism.
    - Created a new hardware test script (test_lines.py) for isolated testing of line detection.
    - Enhanced UI for line calibration and added configuration snippet generation in the TapeTuner class.
    - Modified main.py to initialize line detection and ensure proper setup.
    - Updated launcher.sh to include the new line test option.
    - Fixed minor issues in setup.sh and ui.py for better compatibility and functionality.
    [config.py, game.py, main.py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]
2026-04-30 Refactor calibration logic to improve clarity and encapsulate coordinate transformation
2026-04-30 Refactor calibration logic to use actual frame dimensions for accurate scaling
2026-05-01 Refactor audio playback logic for better handling and add TTS busy check; update camera settings and difficulty parameters for improved gameplay experience
2026-05-05 Update LICENSE to include 3D models licensing
    Added licensing information for 3D models and CAD files under CC BY-NC-SA 4.0.
2026-05-05 Add 3D Files
    [RLGL ARMS.3mf, RLGL BODY.stl, RLGL HEAD.3mf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]

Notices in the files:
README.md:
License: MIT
